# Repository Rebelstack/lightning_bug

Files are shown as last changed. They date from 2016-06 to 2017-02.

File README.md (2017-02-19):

# lightning_bug
EAGLE hardware design and production files for Lightning Bug
# Product Description
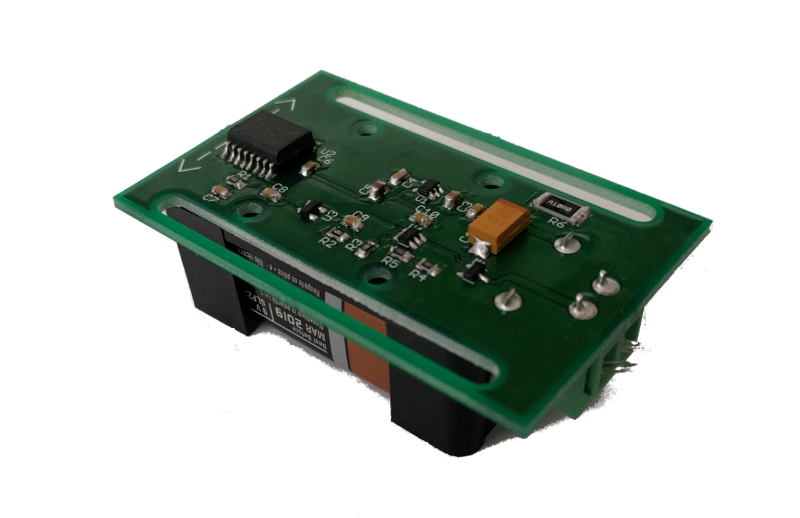
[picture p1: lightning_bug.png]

<br />
Lightning Bug is an acceleration-activated PWM current supply.  Inspired by flying trapeze, 
it is designed to be worn on the body and and connected to a strip of LEDs.  The LEDs are lit
with an intensity that varies with acceleration.  Powered with a standard 9V battery,
Lightning Bug provides a maximum of close to 1A which is divided among the number of
parallel connected LEDs.
# Release Notes
-It is somewhat difficult to insert and remove battery with the battery clip specified.

-R1 and C7 form a low pass recommended by the accelerometer, but may not be necessary 
for this application.  Replace R1 with a 0 Ohm short and do not populate C7 to remove.

-Standard 4-40 screws/nuts can be used to affix the battery clip to the PCB, but two
of the four mounting holes have components close which may interfere.
# Licensing
This work is licensed under a Creative Commons Attribution-ShareAlike 4.0 International License

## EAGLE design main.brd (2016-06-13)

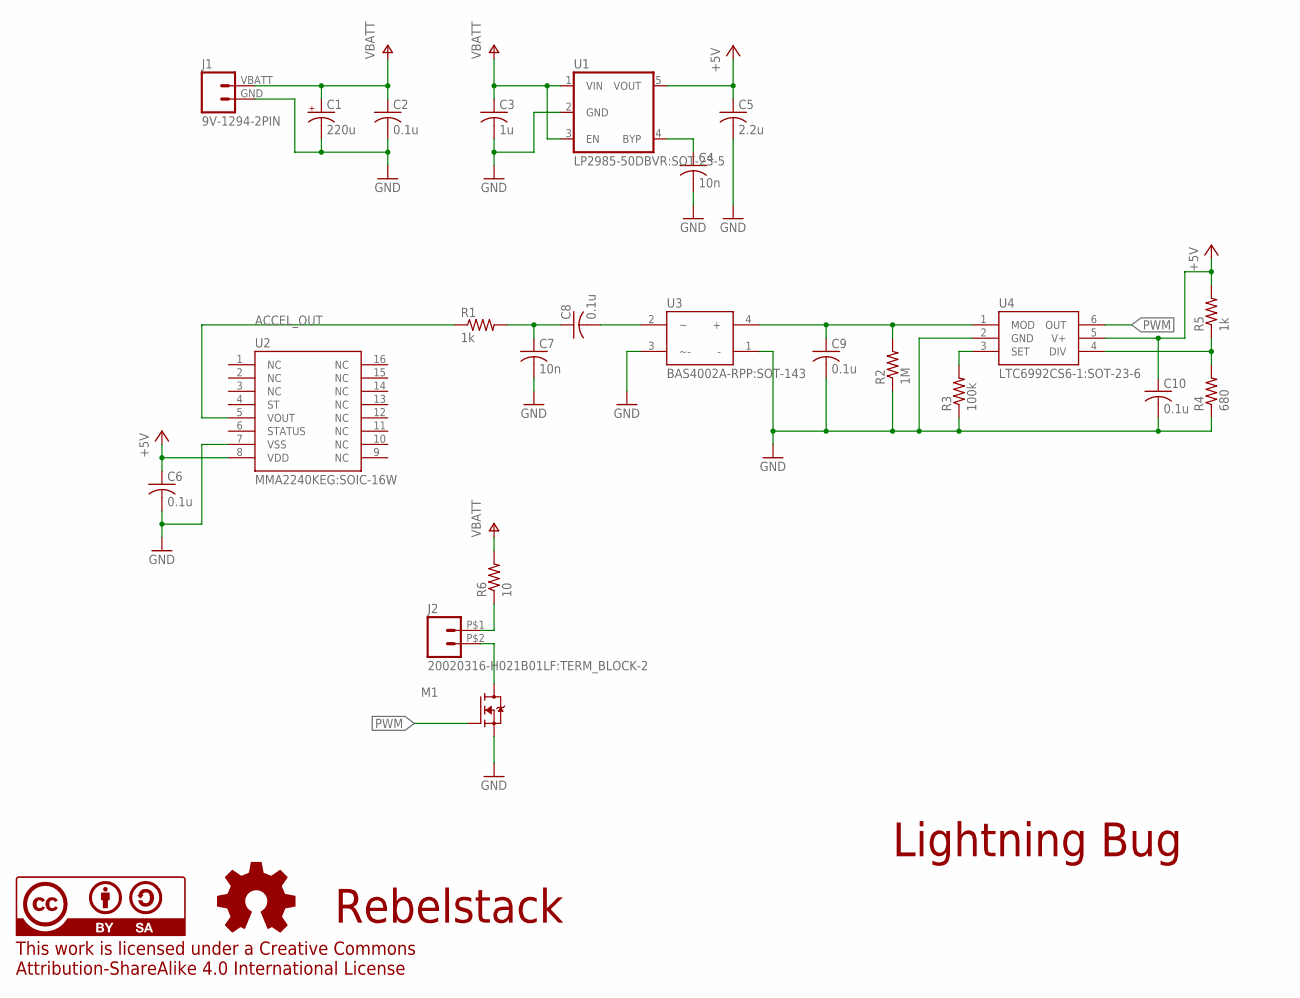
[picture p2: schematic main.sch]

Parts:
C1: 220u; D/7343-31W
C2, C6, C8, C9, C10: 0.1u; C0805
C3: 1u; C0805
C4, C7: 10n; C0805
C5: 2.2u; C0805
J1: 9V-1294-2PIN; 9V-THRU
J2: 20020316-H021B01LF:TERM_BLOCK-2; TERM_BLOCK-2
M1: IRLML2502TRPBF:SOT-23-3; SOT-23-3
R1, R5: 1k; M0805
R2: 1M; M0805
R3: 100k; M0805
R4: 680; M0805
R6: 10; R2512
U1: LP2985-50DBVR:SOT-23-5; SOT-23-5
U2: MMA2240KEG:SOIC-16W; SOIC-16W
U3: BAS4002A-RPP:SOT-143; SOT-143
U4: LTC6992CS6-1:SOT-23-6; SOT-23-6
U$4: CC-BY-SA-4.0-INT-PCB; CC-BY-SA-4.0-INT
U$5: OSHW-LOGO-PCB; OSHW-LOGO

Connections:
+5V: C5.1, C6.1, C10.1, R5.2, U1.5 (VOUT), U2.8 (VDD), U4.5 (V+)
ACCEL_OUT: R1.1, U2.5 (VOUT)
GND: C1.-, C2.2, C3.2, C4.2, C5.2, C6.2, C7.2, C9.2, C10.2, J1.GND (2), M1.2 (S), R2.1, R3.1, R4.1, U1.2 (GND), U2.7 (VSS), U3.1 (-), U3.3 (~-), U4.2 (GND)
unnamed: C4.1, U1.4 (BYP)
unnamed: C8.2, U3.2
unnamed: C9.1, R2.2, U3.4 (+), U4.1 (MOD)
unnamed: R4.2, R5.1, U4.4 (DIV)
unnamed: C7.1, C8.1, R1.2
unnamed: J2.P$1 (1), R6.1
unnamed: R3.2, U4.3 (SET)
unnamed: J2.P$2 (2), M1.3 (D)
PWM: M1.1 (G), U4.6 (OUT)
VBATT: C1.+, C2.1, C3.1, J1.VBATT (1), R6.2, U1.1 (VIN), U1.3 (EN)

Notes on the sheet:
Rebelstack
Lightning Bug

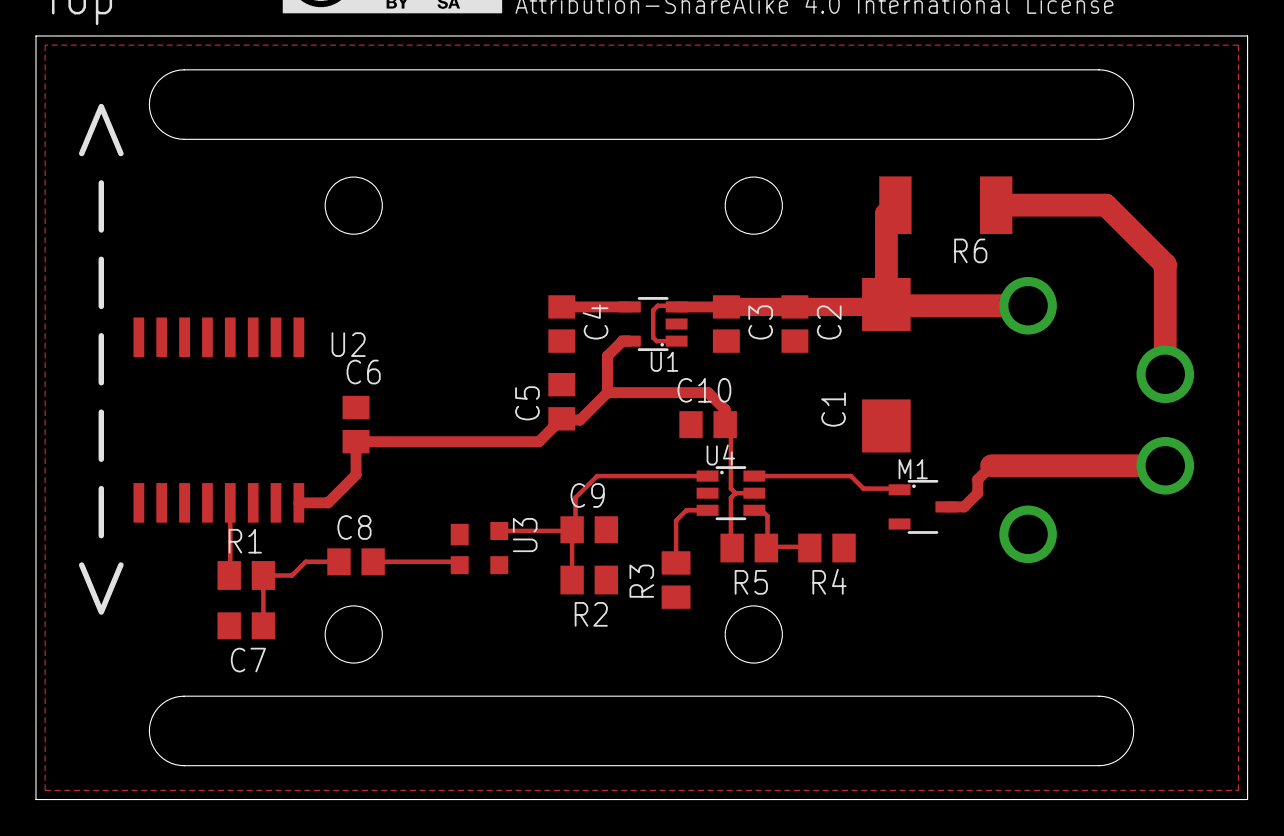
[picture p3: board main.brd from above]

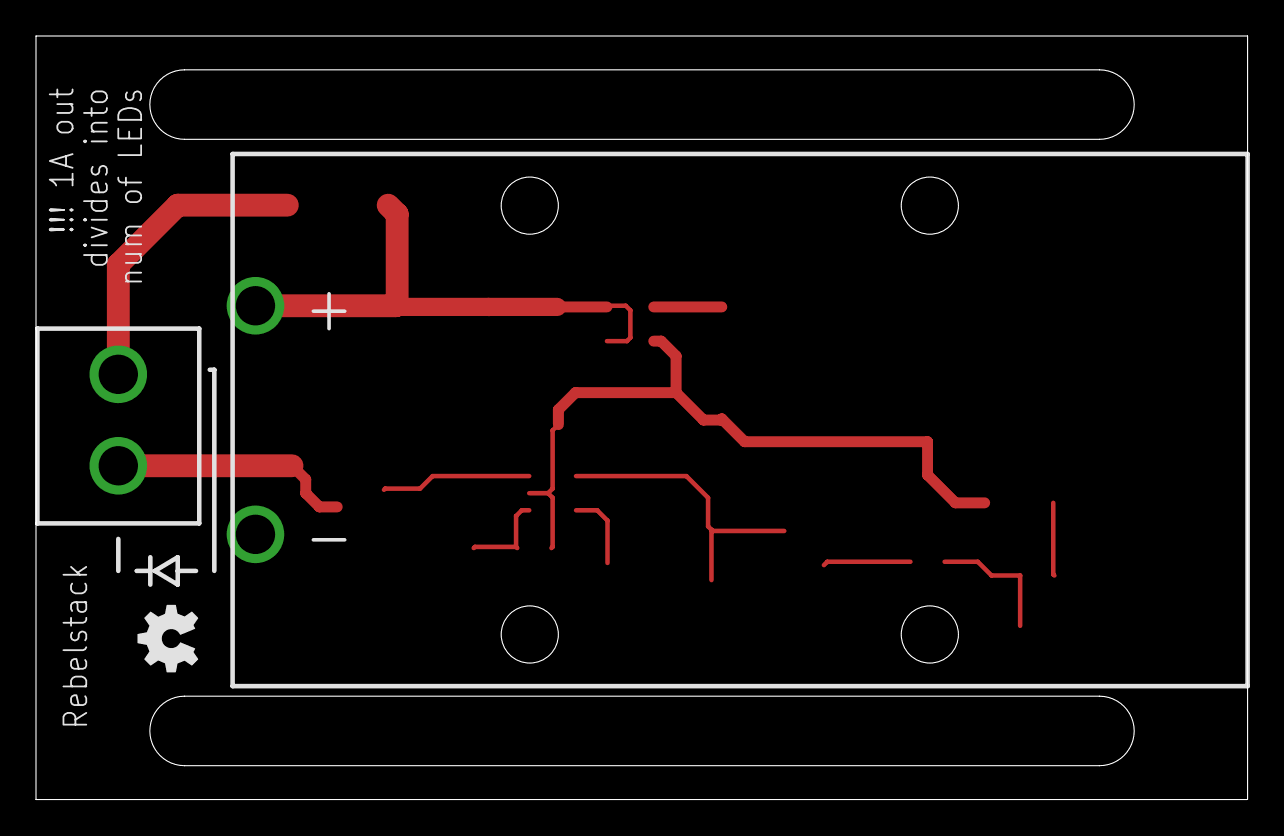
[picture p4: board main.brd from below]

Board: 2 copper layers, 67.3 x 42.4 mm, 25 parts (3 on the bottom side), 13 nets.

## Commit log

2016-06-13 added distributor and distributor p/n attributes to parts
    [main.brd, main.sch]
2016-06-21 adding BOM to project

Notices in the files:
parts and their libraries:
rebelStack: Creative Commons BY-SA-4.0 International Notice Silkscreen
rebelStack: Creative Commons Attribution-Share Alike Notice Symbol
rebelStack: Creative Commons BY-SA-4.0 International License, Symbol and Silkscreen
